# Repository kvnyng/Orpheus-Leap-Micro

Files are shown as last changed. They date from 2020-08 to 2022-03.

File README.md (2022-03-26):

# Orpheus Leap Micro



During the summer of 2020, Hack Club hosted [*Summer of Making*](https://summer.hackclub.com)! It was three months of non-stop hardware hacking! They partnered with GitHub, to give out $50,000 worth of hardware grants and help makers like me!

With that said, to further rep and hype up Summer Of Making, I was asked to design a general-purpose Arduino PCB to commerate the event. With gracious funding from Github and Adafruit, the Orpheus Leap was put into production and 500 were made, shipped, and received by all Summer of Making Hack Clubbers!

This repo holds the Gerber, Eagle files, and documentation for the board. 

# Design

The Orpheus Leap is based off of the Arduino compatible Pro Micro design. Powered by the ATmega32U4, the main features of Orpheus Leap are as follows:

### Features

**Pins**
* 20 I/O pins 
* 7 PWM Channels
* 12 Analog Inputs

**Memory**
* 32 KB Flash Memory (of which 4 KB used for bootloader)
* 2.5 KB SRAM
* 1 KB EEPROM

**Power**
* 5V Logic
* 7-12V input range with VIN pin
* 40 mA output per I/O pin

**Miscellaneous**
* Built-in USB Support (no need for programmer)
* Can act as USB device (keyboard, mouse, game controller, etc)
* A beautiful Orpheus shaped PCB
* ICSP headers for ICSP programming

<!-- # Photos -->
<hr width="50%">

**PCB designed by Kevin Yang, 2020. Supported by Hack Club & GitHub.**

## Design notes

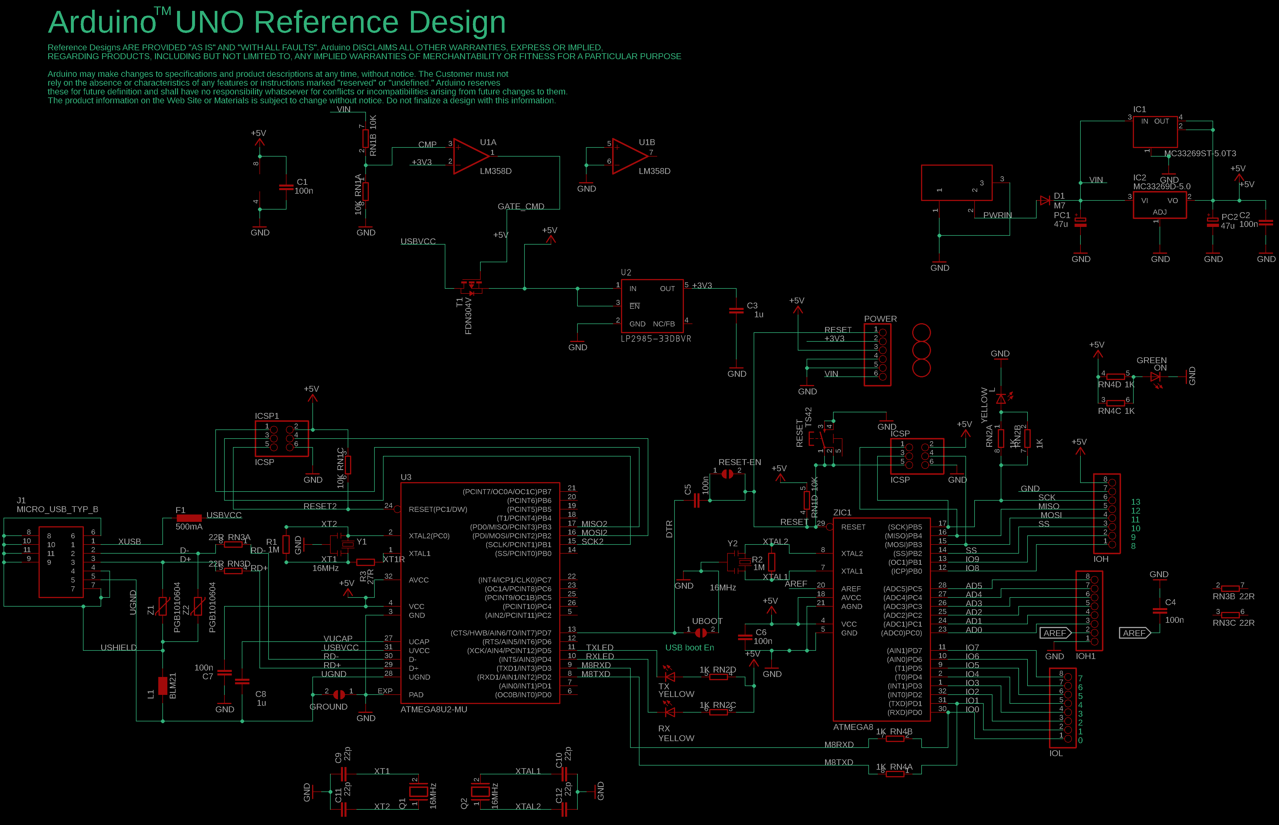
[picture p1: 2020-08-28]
Images/Arduino Micro Schematic.png

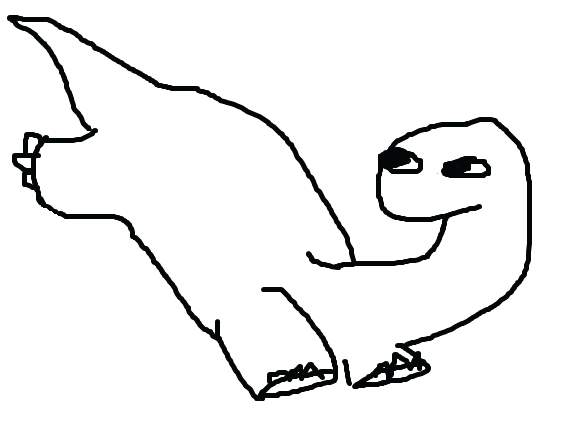
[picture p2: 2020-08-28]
Images/Orpheus Leap Original.png

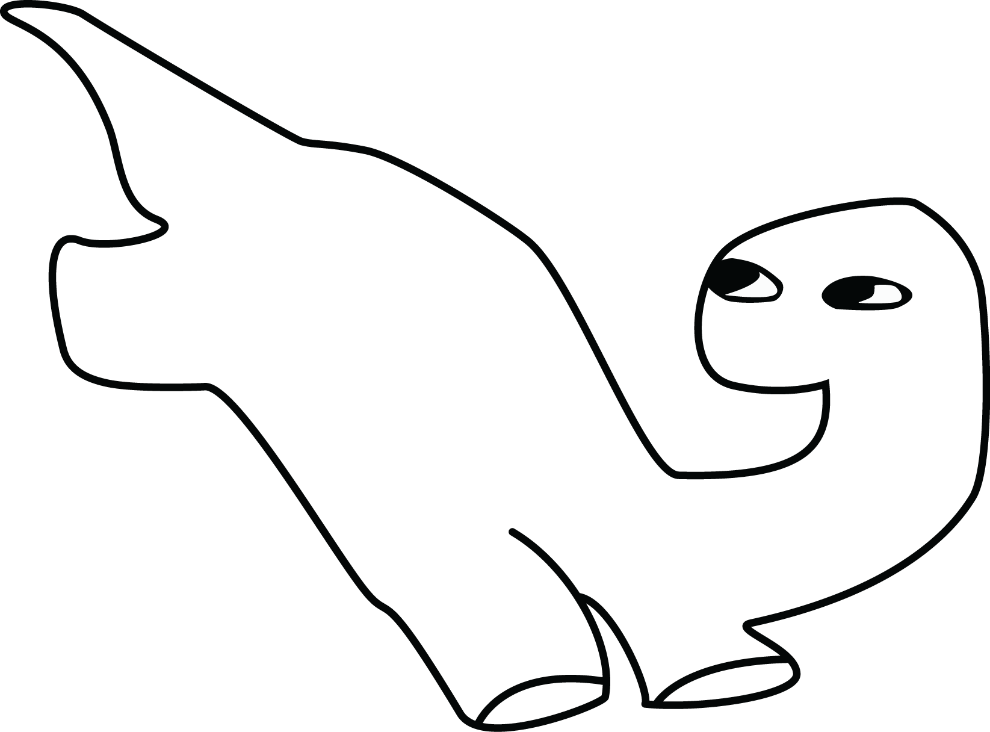
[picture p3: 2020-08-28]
Images/Orpheus Redraw.png

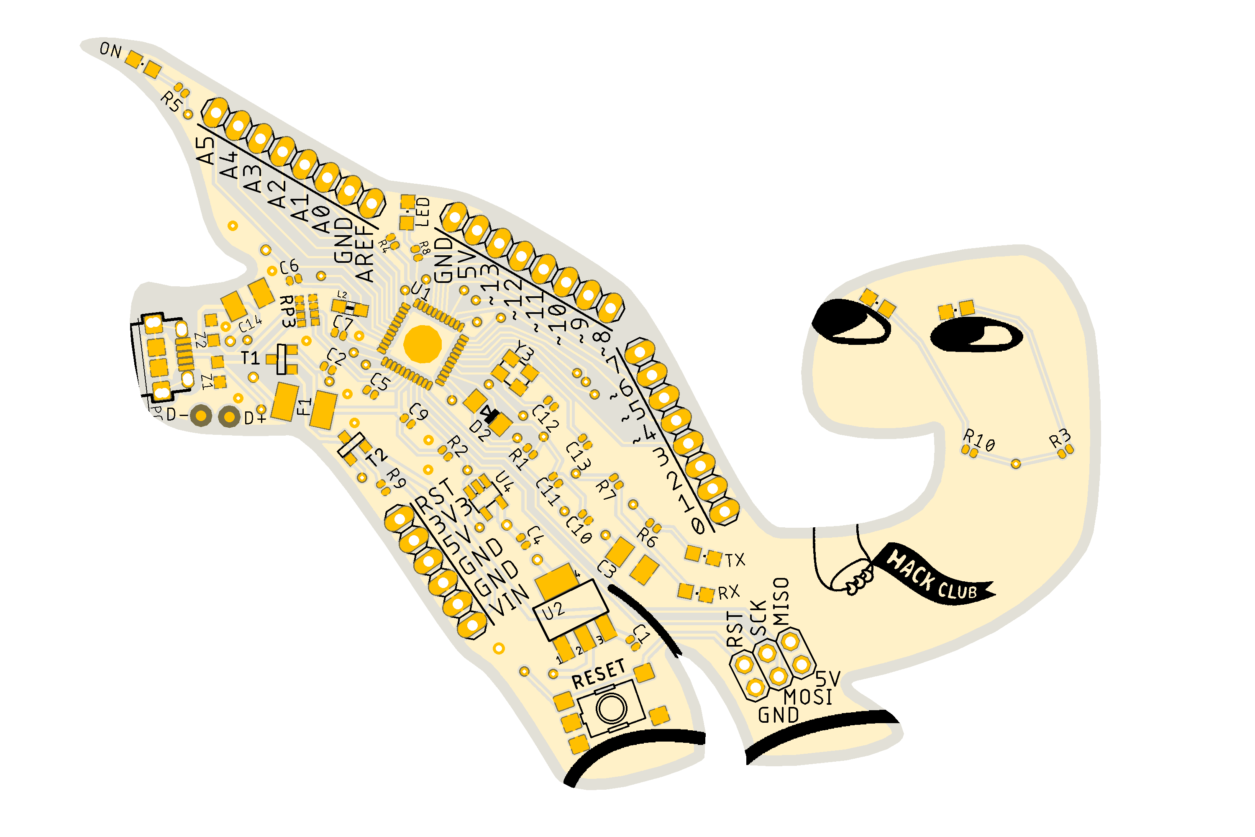
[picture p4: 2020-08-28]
Images/Orpheus Leap PCB (Top).png

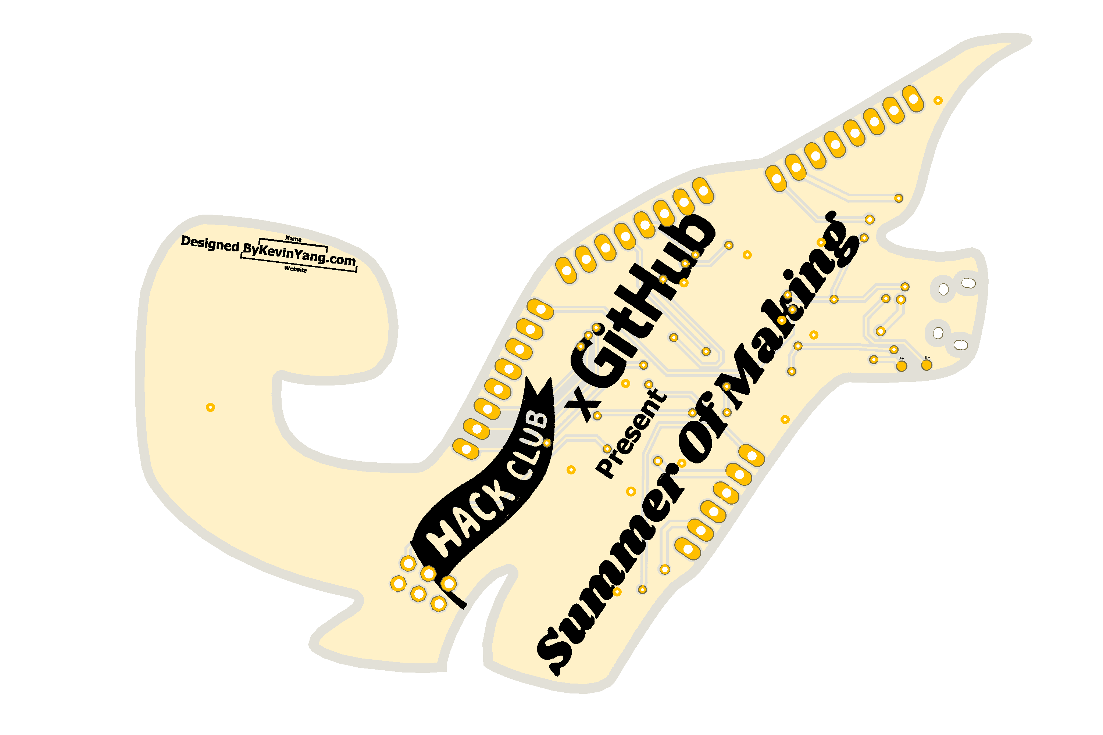
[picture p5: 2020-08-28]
Images/Orpheus Leap PCB (Bottom).png

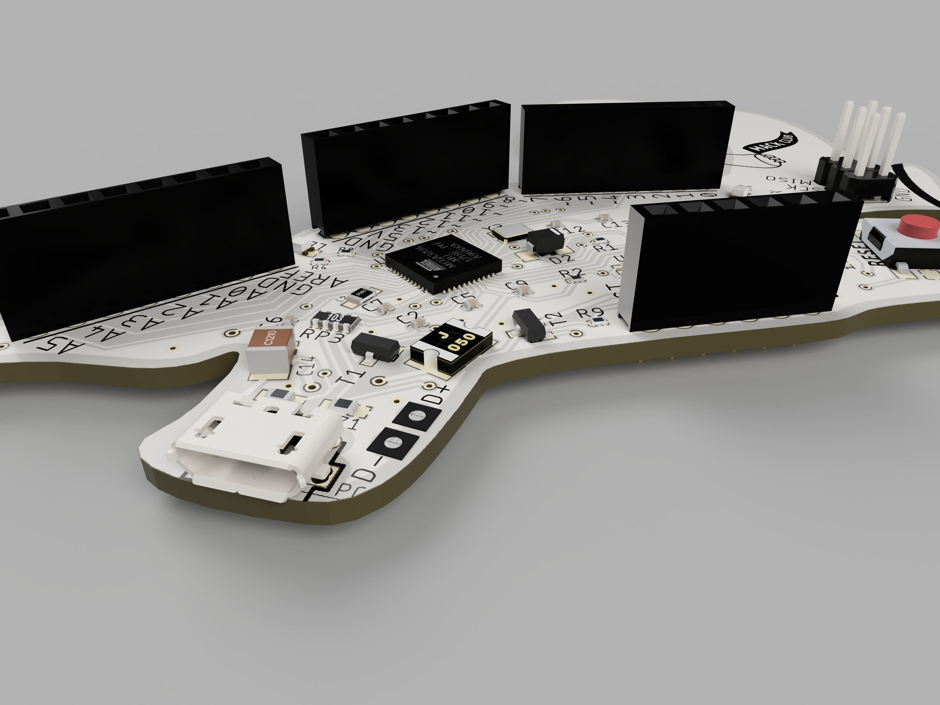
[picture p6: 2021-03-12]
Case/PCB 3D Model - detailed/Renderings/Orpheus_Leap_Micro_2021-Mar-10_08-27-33AM-000_CustomizedView28350227917_png.png

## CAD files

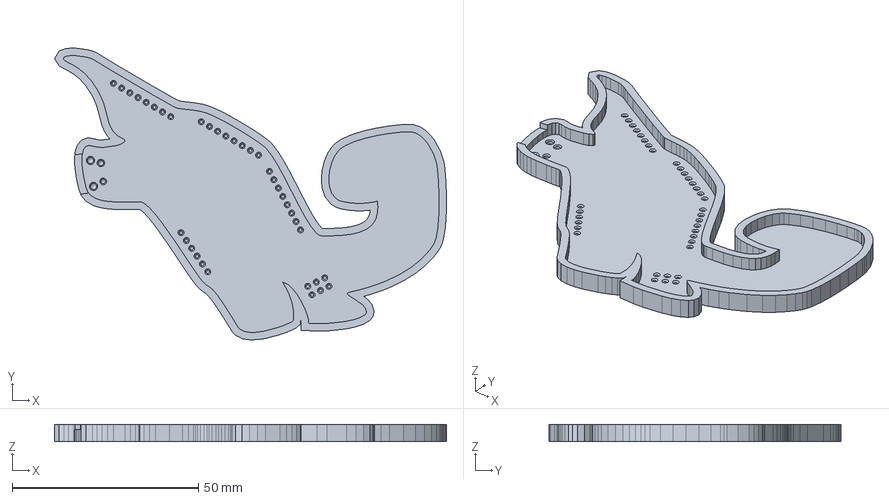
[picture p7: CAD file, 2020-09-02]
Case/Coaster/Coaster Case.step
105.1 x 78.2 x 4.60 mm

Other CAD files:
Case/Coaster/Coaster Case - Updated.stl
Case/Coaster/Coaster Case - Old.stl
Case/Coaster/Coaster Case.f3d

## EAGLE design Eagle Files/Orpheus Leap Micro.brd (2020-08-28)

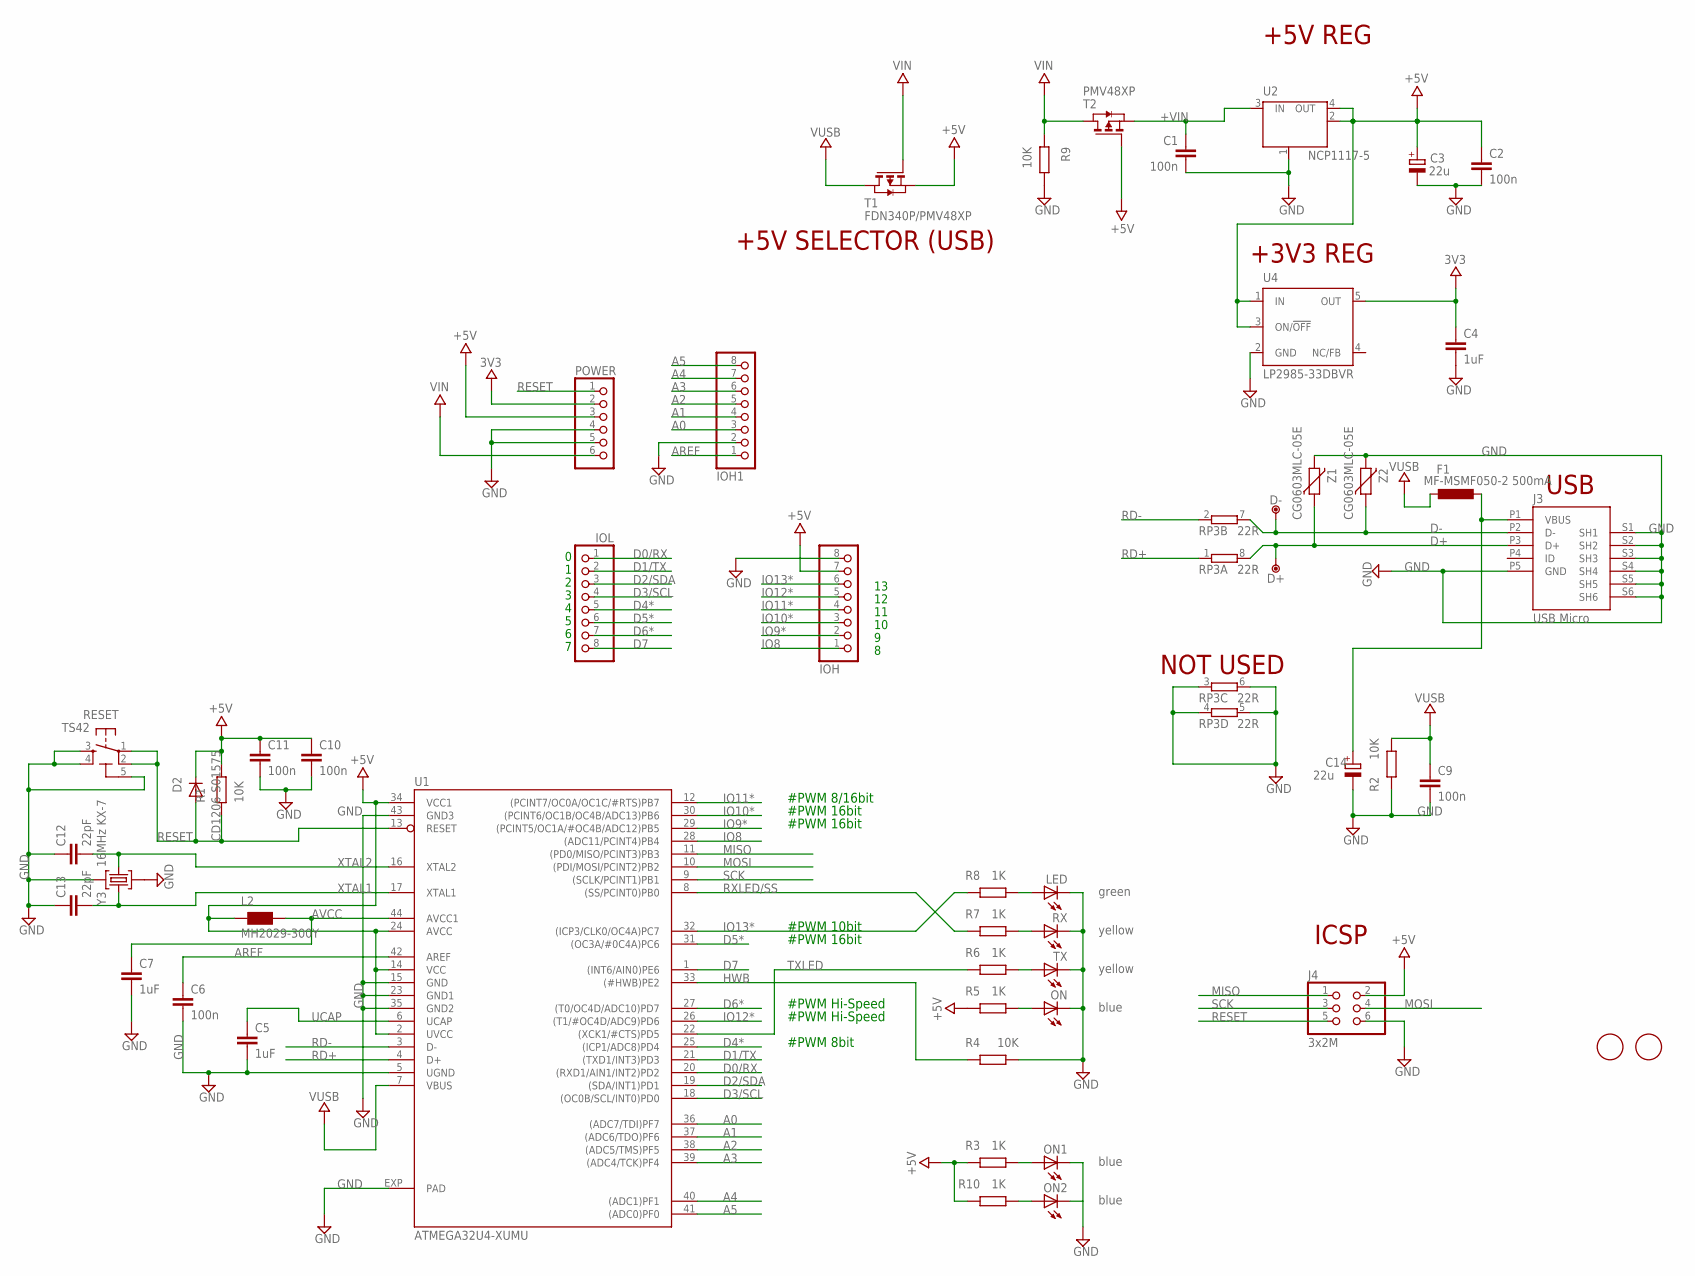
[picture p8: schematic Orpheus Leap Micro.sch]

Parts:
C1, C2, C6, C9, C10, C11: 100n; C0402
C3, C14: 22u; SMC_B
C4, C5, C7: 1uF; C0402
C12, C13: 22pF; C0402
D2: CD1206-S01575; MINIMELF
D+: DNP; TP-1.00MM
D-: DNP; TP-1.00MM
F1: MF-MSMF050-2 500mA; L1812
IOH, IOH1: PINHD-1X8; 1X08
IOL: PINHD-1X8; 1X08
J3: USB Micro; CON2_USB_MICRO_B_AT
J4: 3x2M; 2X03
L2: MH2029-300Y; 0805
LED: green; CHIPLED_0805
ON, ON1, ON2: blue; CHIPLED_0805
POWER: PINHD-1X6; 1X06
R1, R2, R4, R9: 10K; R0402
R3, R5, R6, R7, R8, R10: 1K; R0402
RESET: TS42
RP3: 22R; CAY16
RX: yellow; CHIPLED_0805
T1: FDN340P/PMV48XP; SOT-23
T2: PMV48XP; SOT-23
TX: yellow; CHIPLED_0805
U1: ATMEGA32U4-XUMU; QFN44ML7X7
U2: NCP1117-5; SOT223
U4: LP2985-33DBVR; SOT23-DBV
U$37, U$53: DNP; FD-1-1.5
Y3: 16MHz KX-7; CRYSTAL-3.2-2.5
Z1, Z2: CG0603MLC-05E; CT/CN0603

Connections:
3V3: C4.1, POWER.2, U4.5 (OUT)
+5V: C2.1, C3.+, C10.1, C11.1, D2.C, IOH.7, J4.2, L2.1, POWER.3, R1.1, R3.1, R5.1, R10.1, T1.2 (S), T2.3 (G), U1.2 (UVCC), U1.14 (VCC), U1.24 (AVCC), U1.34 (VCC1), U2.2 (OUT), U2.4 (OUT), U4.1 (IN), U4.3 (ON/!OFF)
+VIN: C1.1, T2.2 (S), U2.3 (IN)
A0: IOH1.3, U1.36 ((ADC7/TDI)PF7)
A1: IOH1.4, U1.37 ((ADC6/TDO)PF6)
A2: IOH1.5, U1.38 ((ADC5/TMS)PF5)
A3: IOH1.6, U1.39 ((ADC4/TCK)PF4)
A4: IOH1.7, U1.40 ((ADC1)PF1)
A5: IOH1.8, U1.41 ((ADC0)PF0)
AREF: C6.1, IOH1.1, U1.42 (AREF)
AVCC: C7.1, L2.2, U1.44 (AVCC1)
D0/RX: IOL.1, U1.20 ((RXD1/AIN1/INT2)PD2)
D1/TX: IOL.2, U1.21 ((TXD1/INT3)PD3)
D2/SDA: IOL.3, U1.19 ((SDA/INT1)PD1)
D3/SCL: IOL.4, U1.18 ((OC0B/SCL/INT0)PD0)
D4*: IOL.5, U1.25 ((ICP1/ADC8)PD4)
D5*: IOL.6, U1.31 ((OC3A/#0C4A)PC6)
D6*: IOL.7, U1.27 ((T0/OC4D/ADC10)PD7)
D7: IOL.8, U1.1 ((INT6/AIN0)PE6)
D+: D+.X, J3.P3 (D+), RP3.8 (2), Z1.1
D-: D-.X, J3.P2 (D-), RP3.7 (2), Z2.1
GND: C1.2, C2.2, C3.-, C4.2, C5.2, C6.2, C7.2, C9.2, C10.2, C11.2, C12.1, C13.1, C14.-, IOH.8, IOH1.2, J3.P5 (GND), J3.S1 (SH1), J3.S2 (SH2), J3.S3 (SH3), J3.S4 (SH4), J3.S5 (SH5), J3.S6 (SH6), J4.6, LED.C, ON.C, ON1.C, ON2.C, POWER.4, POWER.5, R2.1, R4.2, R9.1, RESET.3, RESET.4, RESET.5 (5-GND), RP3.3 (1), RP3.4 (1), RP3.5 (2), RP3.6 (2), RX.C, TX.C, U1.5 (UGND), U1.15 (GND), U1.23 (GND1), U1.35 (GND2), U1.43 (GND3), U1.EXP (PAD), U2.1 (GND/ADJ), U4.2 (GND), Y3.2 (GND), Y3.4 (GND), Z1.2, Z2.2
HWB: R4.1, U1.33 ((#HWB)PE2)
IO8: IOH.1, U1.28 ((ADC11/PCINT4)PB4)
IO9*: IOH.2, U1.29 ((PCINT5/OC1A/#OC4B/ADC12)PB5)
IO10*: IOH.3, U1.30 ((PCINT6/OC1B/OC4B/ADC13)PB6)
IO11*: IOH.4, U1.12 ((PCINT7/OC0A/OC1C/#RTS)PB7)
IO12*: IOH.5, U1.26 ((T1/#OC4D/ADC9)PD6)
IO13*: IOH.6, R8.1, U1.32 ((ICP3/CLK0/OC4A)PC7)
MISO: J4.1, U1.11 ((PD0/MISO/PCINT3)PB3)
MOSI: J4.4, U1.10 ((PDI/MOSI/PCINT2)PB2)
unnamed: ON1.A, R3.2
unnamed: R7.2, RX.A
unnamed: ON.A, R5.2
unnamed: R6.2, TX.A
unnamed: ON2.A, R10.2
unnamed: LED.A, R8.2
RD+: RP3.1, U1.4 (D+)
RD-: RP3.2 (1), U1.3 (D-)
RESET: D2.A, J4.5, POWER.1, R1.2, RESET.1, RESET.2, U1.13 (RESET)
RXLED/SS: R7.1, U1.8 ((SS/PCINT0)PB0)
SCK: J4.3, U1.9 ((SCLK/PCINT1)PB1)
TXLED: R6.1, U1.22 ((XCK1/#CTS)PD5)
UCAP: C5.1, U1.6 (UCAP)
VIN: POWER.6, R9.2, T1.3 (G), T2.1 (D)
VUSB: C9.1, F1.2, R2.2, T1.1 (D), U1.7 (VBUS)
VUSBD: C14.+, F1.1, J3.P1 (VBUS)
XTAL1: C13.2, U1.17 (XTAL1), Y3.3 (C2)
XTAL2: C12.2, U1.16 (XTAL2), Y3.1 (C1)

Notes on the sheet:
+5V REG
ICSP
USB
+5V SELECTOR (USB)
NOT USED
+3V3 REG
#PWM 8bit
#PWM Hi-Speed
#PWM 16bit
#PWM 10bit
#PWM 8/16bit

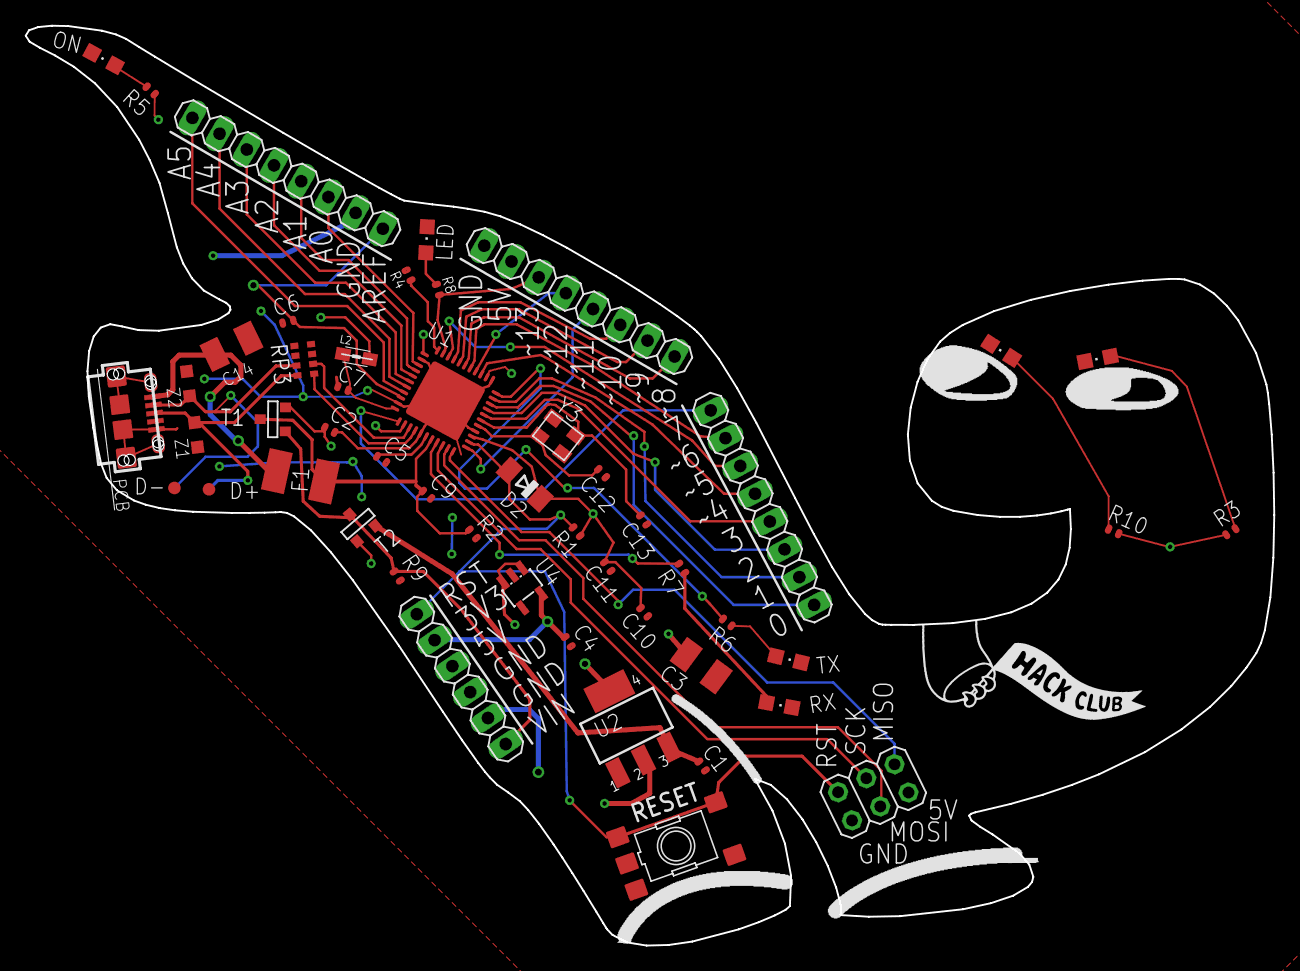
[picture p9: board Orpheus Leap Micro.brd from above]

Board: 2 copper layers, 100.8 x 74.2 mm, 52 parts (0 on the bottom side), 49 nets.

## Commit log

2020-08-28 added files?
    [Orpheus Leap Micro.brd, Orpheus Leap Micro.sch]
2020-09-02 add case
    [Coaster Case - Old.stl, Coaster Case - Updated.stl, Coaster Case.f3d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]
2020-10-02 Update README.md
    add some stuff Kevin left out, which are pretty critical to the purpose of these specially shaped Arduino boards.

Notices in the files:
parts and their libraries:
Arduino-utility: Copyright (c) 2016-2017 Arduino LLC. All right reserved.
